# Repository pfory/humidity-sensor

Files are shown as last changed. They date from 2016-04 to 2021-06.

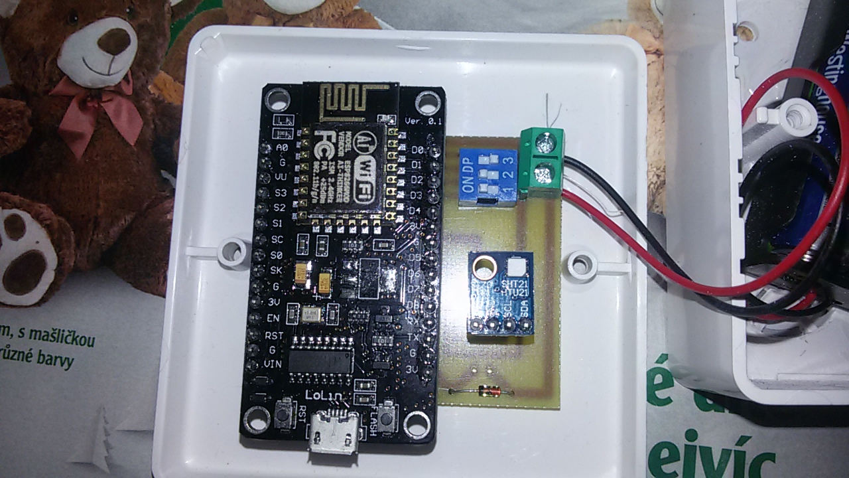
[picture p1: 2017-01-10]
pict/zařízení.jpg

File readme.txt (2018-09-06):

Vlhkomìr
--------
Zaøízení slouží k mìøení vlhkosti a teploty a odesílání hodnot na server xively.com. K pøenosu využívá bezdrátové pøipojení napø. k domácí síti. 
Konfigurace sí�ových adres, xively klíèù a intervalu mìøení je uživatelsky nastavitelná.

Pøepínaèe
Pohled ze strany souèástek 
---------
| O     |   Pøepínaè 3
| O     |   Pøepínaè 2
| O     |   Pøepínaè 1
---------
 ON  OFF
 x - libovolná poloha pøepínaèe

Zaøízení se mùže nacházet ve ètyøech režimech podle nastavení pøepínaèù 1,2 a 3.
            | 2         1           3
------------|------------------------------            
flash       | x         x           OFF
nastavení   | ON        ON          x
test mìøení | OFF       ON          x
mìøení      | OFF       OFF         ON

1. Flash FW
-----------
Pøepínaè 1 je v libovolné poloze, Pøepínaè 2 je v libovolné poloze, Pøepínaè 3 je v poloze OFF.

---------
|     O |   Pøepínaè 3
| x   x |   Pøepínaè 2
| x   x |   Pøepínaè 1
---------
 ON  OFF

Zaøízení musí být pøipojené k napájení, napájení z USB je kvùli spotøebì v režimu spánku vyøazené natrvalo z èinnosti.

2.Nastavení
-----------
Pøepínaè 1 je v poloze ON, Pøepínaè 2 je v poloze ON, Pøepínaè 3 je v libovolné poloze.

---------
| x   x |   Pøepínaè 3
| O     |   Pøepínaè 2
| O     |   Pøepínaè 1
---------
 ON  OFF

Zaøízení se pøepne do režimu AP (pøístupový bod). V seznamu Wifi sítí na PC se zobrazí nový pøístupový bod s názvem ESPHum, heslo pro pøipojení je "humidity007" bez uvozovek. 
Po zadaní adresy 192.168.4.1 v prohlížeèi se zobrazí formuláø pro nastavení sítì:
AP SSID - identifikaèní znak sítì ke které se bude zaøízení pøipojovat. Fusal2
AP PASSWORD - heslo k síti 1860918609
IP - adresa zaøízení napø. 192.168.1.200. Adresa musí být v rozsahu sítì, ke které se pøipojujeme. 192.168.0.93
Maska - sí�ová maska napø. 255.255.255.0
Gateway - brána napø. 192.168.1.1, pøístupový bod do internetu. 192.168.0.1
Prodleva mezi mìøeními - prodleva v sekundách mezi jednotlivými mìøeními. Doporuèuji nastavit více než 300s kvùli výdrži baterií.

Pøed uložením pøepnout Pøepínaè 2 (režim) do polohy ON (mìøení).
Nastavení se uloží a zaøízení se restartuje. Zaøízení je dále v režimu STA (stanice). 

3.Test Mìøení
-------------
Pøepínaè 1 je v poloze ON, Pøepínaè 2 je v poloze OFF, Pøepínaè 3 je v libovolné poloze.
---------
| x   x |   Pøepínaè 3
|     O |   Pøepínaè 2
| O     |   Pøepínaè 1
---------
 ON  OFF

Po zadání adresy IP zaøízení (nastavené v bodì 1.Nastavení) do prohlížeèe se zobrazí formuláø ve kterám se zobrazují namìøené údaje. 
Perioda mìøení je v tomto pøípadì 10s.

Namìøené údaje:
Teplota °C
Vlhkost %Rh
Napìtí baterie V

4.Mìøení
--------
Pøepínaè 1 je v poloze OFF, Pøepínaè 2 v poloze OFF, Pøepínaè 3 je v poloze ON.
---------
| O     |   Pøepínaè 3
|     O |   Pøepínaè 2
|     O |   Pøepínaè 1
---------
 ON  OFF

Zaøízení provede mìøení, výsledky odešle na Xively a upadne do režimu spánku s minimální spotøebou kolem 0,1mA. Po uplynutí nastavené prodlevy se celý cyklus opakuje.
V tomto pøípadì není možné zobrazit webový formuláø v prohlížeèi.

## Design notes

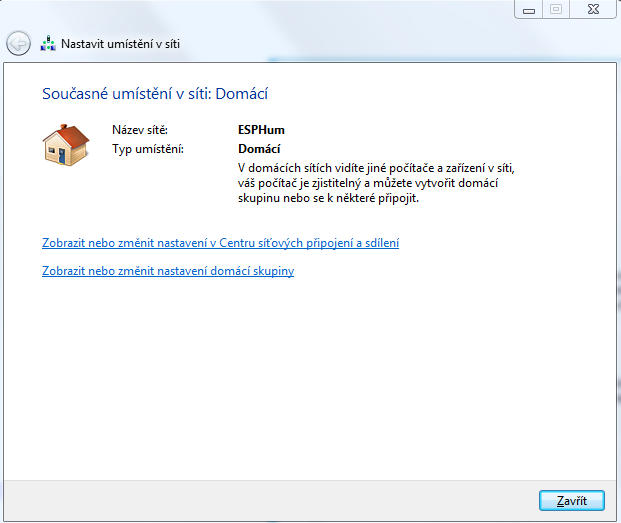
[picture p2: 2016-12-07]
pict/net02.PNG

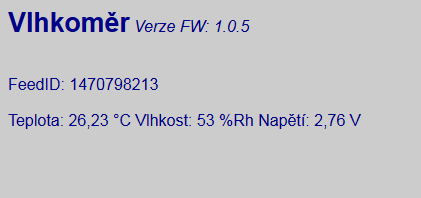
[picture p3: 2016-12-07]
pict/mode3web.PNG

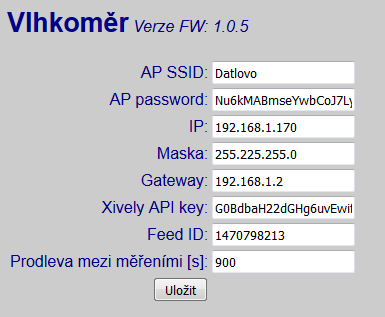
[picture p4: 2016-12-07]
pict/mode2web.PNG

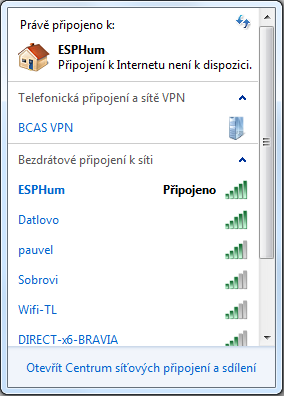
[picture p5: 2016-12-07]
pict/net04.PNG

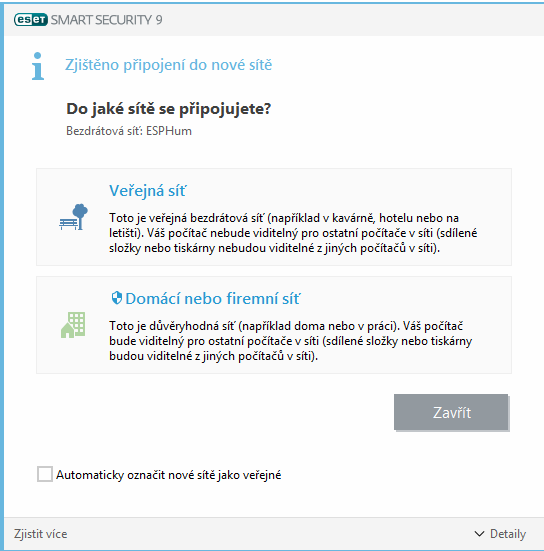
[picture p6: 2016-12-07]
pict/net03.PNG

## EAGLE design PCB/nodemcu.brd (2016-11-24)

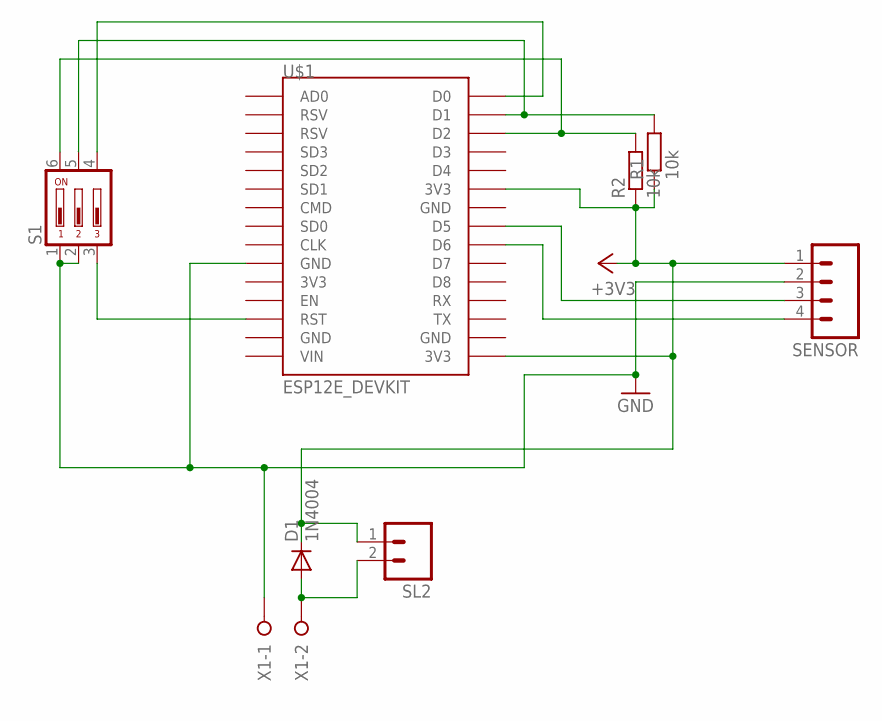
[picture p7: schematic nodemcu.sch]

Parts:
D1: 1N4004; DO41-10
R1, R2: 10k; 0207/10
S1: DIP03YL
SENSOR: M04; 04P
SL2: M02; 02P
U$1: ESP12E_DEVKIT
X1: W237-02P; W237-132

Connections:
+3V3: D1.C, R1.1, R2.1, SENSOR.1, SL2.1, U$1.3V3@1 (3V3), U$1.3V3@2 (3V3)
GND: S1.1, S1.2, SENSOR.2, U$1.GND@0 (GND), X1.1
unnamed: S1.4, U$1.D0
unnamed: SENSOR.4, U$1.D6
unnamed: SENSOR.3, U$1.D5
unnamed: S1.3, U$1.RST
unnamed: D1.A, SL2.2, X1.2
unnamed: R1.2, S1.5, U$1.D1
unnamed: R2.2, S1.6, U$1.D2

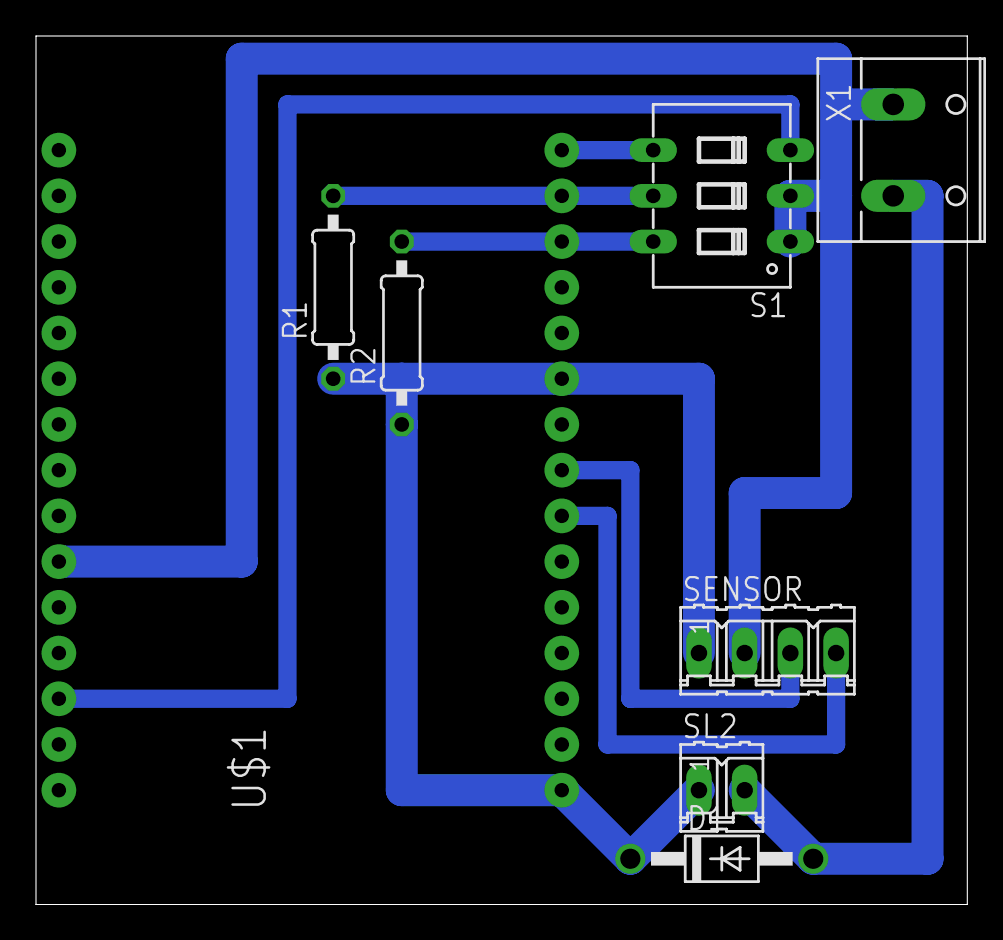
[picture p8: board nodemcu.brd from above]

Board: 2 copper layers, 51.7 x 48.2 mm, 8 parts (0 on the bottom side), 9 nets.

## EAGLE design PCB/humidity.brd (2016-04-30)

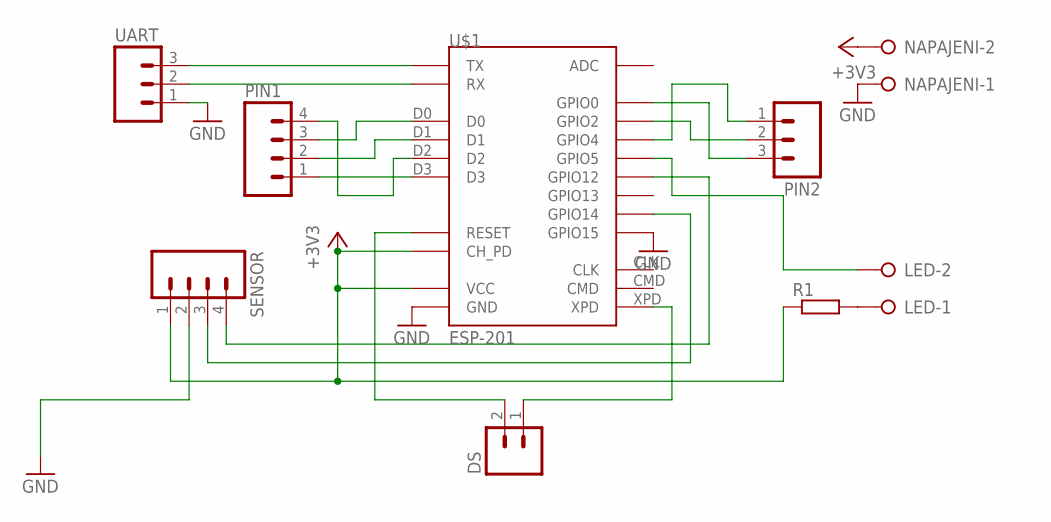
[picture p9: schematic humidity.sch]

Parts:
DS: M02; 02P
LED: W237-02P; W237-132
NAPAJENI: W237-02P; W237-132
PIN1: M04; 04P
PIN2: M03; 03P
R1: R-EU_0207/7; 0207/7
SENSOR: M04; 04P
U$1: ESP-201
UART: M03; 03P

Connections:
+3V3: NAPAJENI.2, R1.1, SENSOR.1, U$1.3V3 (VCC), U$1.3V3_2 (VCC), U$1.3V3_3 (VCC), U$1.CH_PD
GND: NAPAJENI.1, SENSOR.2, U$1.GND, U$1.GND_2 (GND), U$1.GND_3 (GND), U$1.GPIO15, UART.1
unnamed: PIN1.1, U$1.D3
unnamed: DS.2, U$1.RST (RESET)
unnamed: SENSOR.3, U$1.GPIO14
unnamed: SENSOR.4, U$1.GPIO12
unnamed: DS.1, U$1.XPD
unnamed: U$1.TX, UART.3
unnamed: U$1.RX, UART.2
unnamed: PIN1.2, U$1.D1
unnamed: PIN1.3, U$1.D0
unnamed: PIN1.4, U$1.D2
unnamed: PIN2.3, U$1.GPIO0
unnamed: PIN2.2, U$1.GPIO2
unnamed: LED.1, R1.2
unnamed: PIN2.1, U$1.GPIO4
unnamed: LED.2, U$1.GPIO5

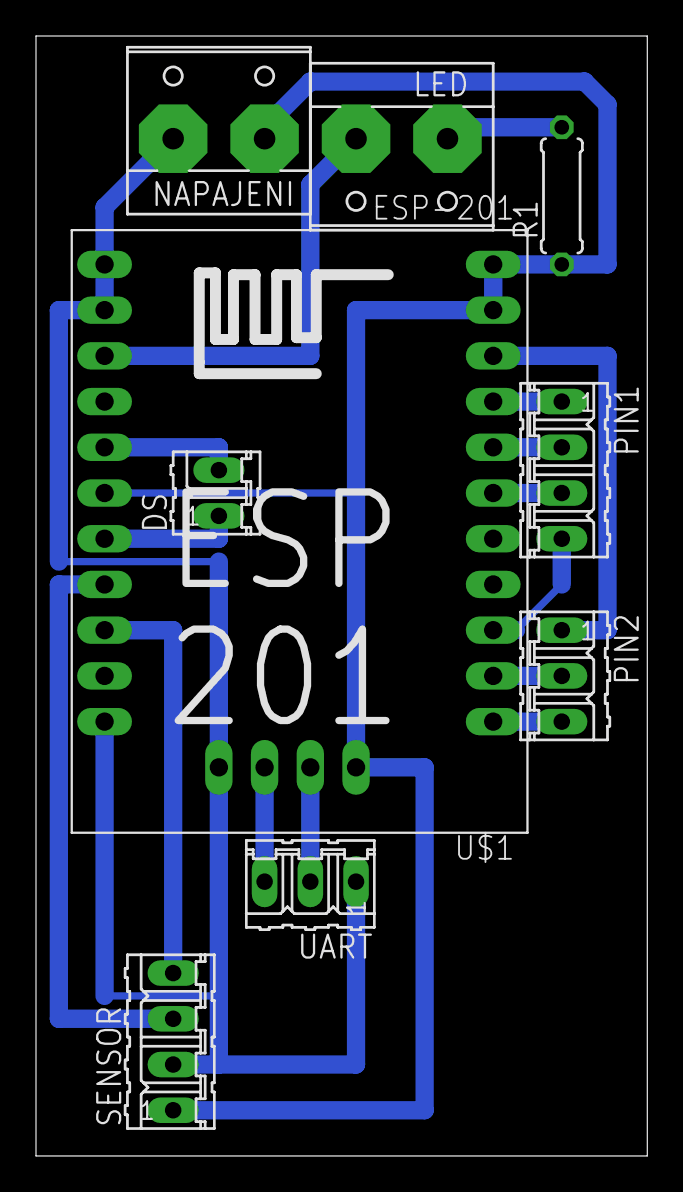
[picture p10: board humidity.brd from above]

Board: 2 copper layers, 34.0 x 62.2 mm, 9 parts (0 on the bottom side), 17 nets.

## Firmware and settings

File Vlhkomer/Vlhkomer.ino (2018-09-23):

unsigned long start=millis();

#include <ESP8266WiFi.h>
#include <SI7021.h>
#include <WiFiClient.h> 
#include <FS.h>
#include "Adafruit_MQTT.h"
#include "Adafruit_MQTT_Client.h"

#define verbose
#ifdef verbose
 #define DEBUG_PRINT(x)         Serial.print (x)
 #define DEBUG_PRINTDEC(x)      Serial.print (x, DEC)
 #define DEBUG_PRINTLN(x)       Serial.println (x)
 #define DEBUG_PRINTF(x, y)     Serial.printf (x, y)
 #define PORTSPEED 115200
#else
 #define DEBUG_PRINT(x)
 #define DEBUG_PRINTDEC(x)
 #define DEBUG_PRINTLN(x)
 #define DEBUG_PRINTF(x, y)
#endif 

ADC_MODE(ADC_VCC);

SI7021 sensor;

#define TEMPERATURE_DIVIDOR 100
#define MILIVOLT_TO_VOLT 1000.0
#define ONECYCLE_IN_MS 1000 
#define TIMEOUTFORWIFI_IN_MS 10000 
#define MICROSECOND 1000000
#define PORTSPEED 115200
#define MILLIS_TO_SEC 1000.0

#define SDA 12 // D6 - GPI12 on ESP-201 module
#define SCL 14 // D5 - GPI14 on ESP-201 module

#include <ESP8266WebServer.h>
ESP8266WebServer serverA(80);

unsigned long const sendDelay = 60000;
unsigned long lastSend = sendDelay;
unsigned long const dispDelay = 5000;
unsigned long lastDisp = dispDelay;
String sleepDelayInSeconds = "60"; 
String ssid;
String passw;
String ip;
String mask;
String gate;

//#define AIO_SERVER      "192.168.1.56"
#define AIO_SERVER      "178.77.238.20"
#define AIO_SERVERPORT  1883
#define AIO_USERNAME    "datel"
#define AIO_KEY         "hanka12"

String brokerIP;
String brokerPort;
String brokerUser;
String brokerPassword;

WiFiClient client;

#define MQTTBASE "/holcik/Vlhkomer3/"

Adafruit_MQTT_Client mqtt(&client, AIO_SERVER, AIO_SERVERPORT, AIO_USERNAME, AIO_KEY);
Adafruit_MQTT_Publish _temperature             = Adafruit_MQTT_Publish(&mqtt, MQTTBASE "Temperature");
Adafruit_MQTT_Publish _humidity                = Adafruit_MQTT_Publish(&mqtt, MQTTBASE "Humidity");
Adafruit_MQTT_Publish _bootTime                = Adafruit_MQTT_Publish(&mqtt, MQTTBASE "bootTime");
Adafruit_MQTT_Publish _voltage                 = Adafruit_MQTT_Publish(&mqtt, MQTTBASE "Voltage");
Adafruit_MQTT_Publish _versionSW               = Adafruit_MQTT_Publish(&mqtt, MQTTBASE "VersionSW");

#define MaxHeaderLength 1600
byte mode=1;
//D1 - prepinac 1 na GPIO5
//D2 - prepinac 2 na GPIO4
//byte mode=1;  //flash
//byte mode=2;  //setup   D1=0 D2=0
//byte mode=3;  //test    D1=1 D2=0
//byte mode=4;  //mereni  D1=1 D2=1

#include "FS.h"


String HttpHeader = String(MaxHeaderLength);
String HttpHeaderBak = String(MaxHeaderLength);

volatile float temperature;
volatile float humidity;
float voltage;

WiFiServer server(80);

float versionSW=1.1;
char versionSWString[] = "Vlhkoměr v"; //SW name & version

void handleRoot() {
	char temp[600];

	snprintf ( temp, 600,
      "<html>\
        <head>\
          <meta http-equiv='refresh' content='5'/>\
          <meta charset='UTF-8'>\
          <title>Vlhkomer</title>\
          <style>\
            body { background-color: #cccccc; font-family: Arial, Helvetica, Sans-Serif; Color: #000088; }\
          </style>\
        </head>\
        <body>\
          <span style='font-weight:bold; font-size:20pt;'>Vlhkoměr</span><span style='font-style:italic;'> Verze FW:1.1 Topic base: %s</span><br/><br/>\
          <p>Teplota: %3d,%02d °C Vlhkost: %3d \%Rh Napětí: %2d,%02d V</p>\
        </body>\
      </html>",
     MQTTBASE,
		 (int)(temperature/TEMPERATURE_DIVIDOR), ((int)temperature)%TEMPERATURE_DIVIDOR, (int)humidity, (int)voltage, ((int)(voltage*100.0))%100
	);
	serverA.send ( 200, "text/html", temp );
}

int readConfig(void);
bool startsWith(const char *, const char *);
String getValue(String, char, int);



void setup() {
  Serial.begin(PORTSPEED);
  DEBUG_PRINT(versionSWString);
  DEBUG_PRINTLN(versionSW);
  //mode
  pinMode(5, INPUT_PULLUP);
  pinMode(4, INPUT_PULLUP);
  int d1 = digitalRead(5);
  int d2 = digitalRead(4);
  
  if (d1==0 && d2==0) {
    mode=2;
  } else if (d1==1 && d2==0) {
    mode = 3;
  } else if (d1==1 && d2==1) {
    mode = 4;
  }
  DEBUG_PRINT("Mode:");
  DEBUG_PRINTLN(mode);

  if (mode==2) { //setup
    delay(1000);
    /* Set these to your desired credentials. */
    const char *ssid;
    const char *password;

    ssid = "ESPHum";
    password = "humidity007";

    DEBUG_PRINTLN();
    DEBUG_PRINT("Configuring access point...");
    /* You can remove the password parameter if you want the AP to be open. */
    WiFi.softAP(ssid, password);

    IPAddress myIP = WiFi.softAPIP();
    DEBUG_PRINT("AP IP address: ");
    DEBUG_PRINTLN(myIP);
    DEBUG_PRINT("SSID: ");
    DEBUG_PRINTLN(ssid);
    DEBUG_PRINT("Password: ");
    DEBUG_PRINTLN(password);
    server.begin();
    DEBUG_PRINTLN("HTTP server started");
    HttpHeader = "";
    
    readConfig();
    
  } else if (mode==3 || mode==4) { //test a mereni
    if (readConfig()>0) {
      DEBUG_PRINTLN("!!!!!!!!!!!!!!!!!!!!!!!!!!!!!!!!!!!!!!!!!!!!!!!!");
      DEBUG_PRINTLN("!!!! Zařízení není nakonfigurované, končím !!!!!");
      DEBUG_PRINTLN("!!!!!!!!!!!!!!!!!!!!!!!!!!!!!!!!!!!!!!!!!!!!!!!!");
      return;
    }
  
    char *pch;
    byte s[HttpHeaderBak.length()];
    HttpHeaderBak.getBytes(s, HttpHeaderBak.length());
    DEBUG_PRINTLN(HttpHeaderBak);
    pch = strtok((char*)s,"?&=");
    while (pch != NULL) {
     DEBUG_PRINTLN(pch);
    if (startsWith("ssid",pch)) {
      ssid=strchr(pch,'=')+1;
    }
    if (startsWith("passw",pch)) {
      passw=strchr(pch,'=')+1;
    }
    if (startsWith("ip",pch)) {
      ip=strchr(pch,'=')+1;
    }
    if (startsWith("mask",pch)) {
      mask=strchr(pch,'=')+1;
    }
    if (startsWith("gateway",pch)) {
      gate=strchr(pch,'=')+1;
    }

    // if (startsWith("brokerIP",pch)) {
      // brokerIP=strchr(pch,'=')+1;
    // }
    // if (startsWith("brokerPort",pch)) {
      // brokerPort=strchr(pch,'=')+1;
    // }
    // if (startsWith("brokerUser",pch)) {
      // brokerUser=strchr(pch,'=')+1;
    // }
    // if (startsWith("brokerPassword",pch)) {
      // brokerPassword=strchr(pch,'=')+1;
    // }

    if (startsWith("delay",pch)) {
      sleepDelayInSeconds=strchr(pch,'=')+1;
    }
    pch = strtok (NULL, "&");
    }

    IPAddress _ip(getValue(ip, '.', 0).toInt(), getValue(ip, '.', 1).toInt(), getValue(ip, '.', 2).toInt(), getValue(ip, '.', 3).toInt());
    IPAddress _gateway(getValue(gate, '.', 0).toInt(), getValue(gate, '.', 1).toInt(), getValue(gate, '.', 2).toInt(), getValue(gate, '.', 3).toInt());
    IPAddress _mask(getValue(mask, '.', 0).toInt(), getValue(mask, '.', 1).toInt(), getValue(mask, '.', 2).toInt(), getValue(mask, '.', 3).toInt());

    // Adafruit_MQTT_Client mqtt(&client, brokerIP.c_str(), (uint16_t)brokerPort.toInt(), brokerUser.c_str(), brokerPassword.c_str());
    /****************************** Feeds ***************************************/
    // Adafruit_MQTT_Publish _temperature             = Adafruit_MQTT_Publish(&mqtt, "/holcik/Vlhkomer5/Temperature");
    // Adafruit_MQTT_Publish _humidity                = Adafruit_MQTT_Publish(&mqtt, "/holcik/Vlhkomer5/Humidity");
    // Adafruit_MQTT_Publish _versionSW               = Adafruit_MQTT_Publish(&mqtt, "/holcik/Vlhkomer5/VersionSW");
    
    WiFi.mode(WIFI_STA);
    WiFi.config(_ip, _gateway, _mask);
    
    char _ssid[ssid.length()+1];
    char _passw[passw.length()+1];
    ssid.toCharArray(_ssid, ssid.length()+1);
    passw.toCharArray(_passw, passw.length()+1); 
    
    DEBUG_PRINTLN(_ssid);
    DEBUG_PRINTLN(_passw);

    WiFi.begin(_ssid, _passw);

    byte cyklu=0;  
    while (WiFi.status() != WL_CONNECTED) {
      cyklu++;
      delay(ONECYCLE_IN_MS);
      DEBUG_PRINT(".");
      if (cyklu*ONECYCLE_IN_MS>TIMEOUTFORWIFI_IN_MS) {
        DEBUG_PRINTLN();
        if (mode==3) {
          DEBUG_PRINT("Wifi unavailable, restart.");
          ESP.restart();
        } else {
          DEBUG_PRINT("Wifi unavailable, go to deepsleep for 5 minutes");
          ESP.deepSleep(300 * MICROSECOND, WAKE_RF_DEFAULT);
        }
      }
    }
    
    if (mode==4) {
      while (WiFi.status() != WL_CONNECTED) {
        cyklu++;
        delay(ONECYCLE_IN_MS);
        DEBUG_PRINT(".");
        if (cyklu*ONECYCLE_IN_MS>TIMEOUTFORWIFI_IN_MS) {
          DEBUG_PRINTLN();
          DEBUG_PRINT("Wifi unavailable, go to deepsleep for 5 minutes");
          ESP.deepSleep(300 * MICROSECOND, WAKE_RF_DEFAULT);
        }
      }
    }

    DEBUG_PRINTLN("");
    DEBUG_PRINTLN("WiFi connected");  
    DEBUG_PRINT("IP address: ");
    DEBUG_PRINTLN(WiFi.localIP());
    DEBUG_PRINT("Gateway: ");
    DEBUG_PRINTLN(WiFi.gatewayIP());
    DEBUG_PRINT("Subnet: ");
    DEBUG_PRINTLN(WiFi.subnetMask());
    DEBUG_PRINT("MAC: ");
    DEBUG_PRINTLN(WiFi.macAddress());
    DEBUG_PRINT("Interval: ");
    DEBUG_PRINT(sleepDelayInSeconds);
    DEBUG_PRINTLN(" seconds");

    sensor.begin(SDA,SCL);
    serverA.on ( "/", handleRoot );
  	serverA.begin();
    DEBUG_PRINTLN ( "HTTP server started" );
  }
}

void loop() {
  if (mode==2) {
    WiFiClient client = server.available();
      
    if (client) {
      while (client.connected()) {
        if (client.available()) {
           char c = client.read();
           //read MaxHeaderLength number of characters in the HTTP header
           //discard the rest until \n
           if (HttpHeader.length() < MaxHeaderLength) {
             //store characters to string
             HttpHeader = HttpHeader + c;
           }
           //if HTTP request has ended
           if (c == '\n') {
             if (HttpHeaderBak.length()>0) {
               HttpHeader=HttpHeaderBak;
               HttpHeaderBak="";
             }
             
             String key;
             
             char *pch;
             byte s[HttpHeader.length()];
             HttpHeader.getBytes(s, HttpHeader.length());
             pch = strtok((char*)s,"?&=");
             while (pch != NULL) {
               DEBUG_PRINTLN(pch);
              if (startsWith("ssid",pch)) {
                ssid=strchr(pch,'=')+1;
              }
              if (startsWith("passw",pch)) {
                passw=strchr(pch,'=')+1;
              }
              if (startsWith("ip",pch)) {
                ip=strchr(pch,'=')+1;
              }
              if (startsWith("mask",pch)) {
                mask=strchr(pch,'=')+1;
              }
              if (startsWith("gateway",pch)) {
                gate=strchr(pch,'=')+1;
              }
              // if (startsWith("brokerIP",pch)) {
                // brokerIP=strchr(pch,'=')+1;
              // }
              // if (startsWith("brokerPort",pch)) {
                // brokerPort=strchr(pch,'=')+1;
              // }
              // if (startsWith("brokerUser",pch)) {
                // brokerUser=strchr(pch,'=')+1;
              // }
              // if (startsWith("brokerPassword",pch)) {
                // brokerPassword=strchr(pch,'=')+1;
              // }
              if (startsWith("delay",pch)) {
                sleepDelayInSeconds=strchr(pch,'=')+1;
              }
              pch = strtok (NULL, "&");
             }

             
             // client.println("HTTP/1.1 200 OK");
             // client.println("Content-Type: text/html");
             // client.println("<html><head><meta charset='UTF-8'></head><body>");
             // client.println();
             client.print("<html><head><meta charset='UTF-8'></head><style> body { background-color: #cccccc; font-family: Arial, Helvetica, Sans-Serif; Color: #000088; }</style>");
             client.print("<form>");
             client.print("<span style='font-weight:bold; font-size:20pt;'>Vlhkoměr</span><span style='font-style:italic;'>v");
             client.print(versionSW);
             client.print("Topic base: ");
             client.print(MQTTBASE);             
             client.print("</span><br/><br/>");
             client.print("<table><tr><td style='text-align:right;'>AP SSID:</td><td><input type='text' name=ssid value='");
             client.print(ssid);
             client.print("'/></td></tr>");
             client.print("<tr><td style='text-align:right;'>AP password:</td><td><input type='text' name=passw value='" + passw + "'/></td></tr>");
             client.print("<tr><td style='text-align:right;'>IP:</td><td><input type='text' name='ip' maxlength='15' value='" + ip + "'/></td></tr>");
             client.print("<tr><td style='text-align:right;'>Maska:</td><td><input type='text' name='mask' maxlength='15' value='" + mask + "'/></td></tr>");
             client.print("<tr><td style='text-align:right;'>Gateway:</td><td><input type='text' name='gateway' maxlength='15' value='" + gate + "'/></td></tr>");
             // client.print("<tr><td style='text-align:right;'>MQTT Broker IP:</td><td><input type='text' name='brokerIP' maxlength='15' value='" + brokerIP + "'/></td></tr>");
             // client.print("<tr><td style='text-align:right;'>MQTT Broker port:</td><td><input type='text' name='brokerPort' maxlength='5' value='" + brokerPort + "'/></td></tr>");
             // client.print("<tr><td style='text-align:right;'>MQTT Broker user:</td><td><input type='text' name='brokerUser' maxlength='15' value='" + brokerUser + "'/></td></tr>");
             // client.print("<tr><td style='text-align:right;'>MQTT Broker password:</td><td><input type='text' name='brokerPassword' maxlength='15' value='" + brokerPassword + "'/></td></tr>");
             client.print("<tr><td style='text-align:right;'>Prodleva mezi měřeními [s]:</td><td><input type='text' name='delay' maxlength='5' value='" + sleepDelayInSeconds + "'/></td></tr>");
             client.print("<tr><td style='text-align:right'><input type=submit name=ulozit value='Uložit'></td>");
             // client.print("<td style='text-align:right'><input type=submit name=reset value='Reset'></td></tr>");
             client.print("</table></form>");
             client.print("</body></html>");

             if (HttpHeader.indexOf('?') > 0) {
              // open file for writing
              File f = SPIFFS.open("/config.txt", "w");
              if (!f) {
                  DEBUG_PRINTLN("file open failed");
              }
              DEBUG_PRINTLN("====== Writing to SPIFFS file =========");
              DEBUG_PRINT("HttpHeader:");
              DEBUG_PRINTLN(HttpHeader);
              // write 10 strings to file
              f.println(HttpHeader);
              f.close();
             }
             //clearing string for next read
             HttpHeader="";
             //stopping client
             client.stop();
          }
        }
      }
    }
  } else if (mode==3 || mode==4) {
    temperature=sensor.getCelsiusHundredths();
    humidity=sensor.getHumidityPercent();
    if (millis() - lastDisp >= dispDelay) {
      lastDisp = millis();
      DEBUG_PRINT("Temperature:");
      DEBUG_PRINT(temperature/TEMPERATURE_DIVIDOR);
      DEBUG_PRINTLN("C");
      DEBUG_PRINT("Humidity:");
      DEBUG_PRINT(humidity);
      DEBUG_PRINTLN("%");
      voltage = (float)ESP.getVcc()/MILIVOLT_TO_VOLT;
      DEBUG_PRINT("Voltage:");
      DEBUG_PRINT(voltage);
      DEBUG_PRINTLN("V");
      DEBUG_PRINTLN();
    }
    if (mode==3) {
      serverA.handleClient();
    }
    if (millis() - lastSend >= sendDelay) {
      lastSend = millis();
      //send MQTT data
      sendDataHA();
    }
    if (mode==4) { //mererni
      DEBUG_PRINT("Start duration:");
      DEBUG_PRINT(millis()-start);
      DEBUG_PRINTLN(" ms.");
      DEBUG_PRINTLN("Entering deep sleep mode.");
      DEBUG_PRINT("Wake in ");
      DEBUG_PRINT(sleepDelayInSeconds);
      DEBUG_PRINTLN(" s.");
      delay(2000);
      ESP.deepSleep(sleepDelayInSeconds.toInt() * MICROSECOND, WAKE_RF_DEFAULT);
    }
  }
}

bool startsWith(const char *pre, const char *str) {
    size_t lenpre = strlen(pre),
           lenstr = strlen(str);
    return lenstr < lenpre ? false : strncmp(pre, str, lenpre) == 0;
}


int readConfig() {
  DEBUG_PRINTLN("Read config file.");
  SPIFFS.begin();
  // open file for reading
  File f = SPIFFS.open("/config.txt", "r");
  if (!f) {
    DEBUG_PRINTLN("file open failed");
    return 1;
  } else {
    DEBUG_PRINTLN("====== Reading from SPIFFS file =======");
    HttpHeaderBak=f.readStringUntil('\n');
    DEBUG_PRINTLN(HttpHeaderBak);
  }
  return 0;
}


String getValue(String data, char separator, int index) {
  int found = 0;
  int strIndex[] = {0, -1};
  int maxIndex = data.length()-1;

  for(int i=0; i<=maxIndex && found<=index; i++){
    if(data.charAt(i)==separator || i==maxIndex){
        found++;
        strIndex[0] = strIndex[1]+1;
        strIndex[1] = (i == maxIndex) ? i+1 : i;
    }
  }

  return found>index ? data.substring(strIndex[0], strIndex[1]) : "";
}

void sendDataHA() {
  DEBUG_PRINTLN(" I am sending data from humidity and temperature sensor to HomeAssistant");
  MQTT_connect();
  if (! _temperature.publish(temperature/TEMPERATURE_DIVIDOR)) {
    DEBUG_PRINTLN("Temperature failed");
  } else {
    DEBUG_PRINTLN("Temperature OK!");
  }  
  if (! _humidity.publish(humidity)) {
    DEBUG_PRINTLN("Humidity failed");
  } else {
    DEBUG_PRINTLN("Humidity OK!");
  }  
  if (! _voltage.publish(voltage)) {
    DEBUG_PRINTLN("Voltage failed");
  } else {
    DEBUG_PRINTLN("Voltage OK!");
  }  
  if (! _bootTime.publish((uint8_t)(millis()-start))) {
    DEBUG_PRINTLN("BootTime failed");
  } else {
    DEBUG_PRINTLN("BootTime OK!");
  }  
  if (! _versionSW.publish(versionSW)) {
    DEBUG_PRINTLN("Version SW failed");
  } else {
    DEBUG_PRINTLN("Version SW OK!");
  }  
}
 
void MQTT_connect() {
  int8_t ret;

  // Stop if already connected.
  if (mqtt.connected()) {
    return;
  }

  DEBUG_PRINT("Connecting to MQTT... ");

  uint8_t retries = 3;
  while ((ret = mqtt.connect()) != 0) { // connect will return 0 for connected
       DEBUG_PRINTLN(mqtt.connectErrorString(ret));
       DEBUG_PRINTLN("Retrying MQTT connection in 5 seconds...");
       mqtt.disconnect();
       delay(5000);  // wait 5 seconds
       retries--;
       if (retries == 0) {
         // basically die and wait for WDT to reset me
         while (1);
       }
  }
  DEBUG_PRINTLN("MQTT Connected!");
}

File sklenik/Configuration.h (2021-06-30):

#ifndef CONFIGURATION_H
#define CONFIGURATION_H

#include <ESP8266WiFi.h>              //https://github.com/esp8266/Arduino
#include <WiFiManager.h>              //https://github.com/tzapu/WiFiManager
#include "Sender.h"
#include <DoubleResetDetector.h>      //https://github.com/khoih-prog/ESP_DoubleResetDetector
#include <Ticker.h>
#include "SI7021.h"                   //https://github.com/LowPowerLab/SI7021.git


//SW name & version
#define     VERSION                      "0.20"
#define     SW_NAME                      "VlhkomerSklenik"

//#define timers
#define verbose
//#define time
#ifdef time
#include <TimeLib.h>
#include <Timezone.h>
#endif

#define AUTOCONNECTPWD    "password"

//#define ota
#ifdef ota
#include <ArduinoOTA.h>
#define HOSTNAMEOTA       SW_NAME VERSION
#define AUTOCONNECTNAME   HOSTNAMEOTA
#else
#define AUTOCONNECTNAME   SW_NAME VERSION
#endif

/*
--------------------------------------------------------------------------------------------------------------------------

Version history:

--------------------------------------------------------------------------------------------------------------------------
HW
ESP8266 Wemos D1
HC-SR04
*/


#define verbose
#ifdef verbose
  #define DEBUG_PRINT(x)         Serial.print (x)
  #define DEBUG_PRINTDEC(x)      Serial.print (x, DEC)
  #define DEBUG_PRINTLN(x)       Serial.println (x)
  #define DEBUG_PRINTF(x, y)     Serial.printf (x, y)
  #define DEBUG_PRINTHEX(x)      Serial.print (x, HEX)
  #define PORTSPEED 115200
  #define SERIAL_BEGIN           Serial.begin(PORTSPEED);
#else
  #define DEBUG_PRINT(x)
  #define DEBUG_PRINTDEC(x)
  #define DEBUG_PRINTLN(x)
  #define DEBUG_PRINTF(x, y)
#endif 


// Number of seconds after reset during which a
// subseqent reset will be considered a double reset.
#define DRD_TIMEOUT 2
// RTC Memory Address for the DoubleResetDetector to use
#define DRD_ADDRESS 0

#define CONFIG_PORTAL_TIMEOUT 60 //jak dlouho zustane v rezimu AP nez se cip resetuje
#define CONNECT_TIMEOUT 120 //jak dlouho se ceka na spojeni nez se aktivuje config portal

static const char* const      mqtt_server                    = "192.168.1.56";
static const uint16_t         mqtt_port                      = 1883;
static const char* const      mqtt_username                  = "datel";
static const char* const      mqtt_key                       = "hanka12";
static const char* const      mqtt_base                      = "/home/sklenik/esp10";


int                           voltage                        = 0; //voltage in mV
uint32_t                      lastRun                        = 0;
int                           temperature                    = 0;
uint8_t                       humidity                       = 0;
uint32_t                      deepSleepMicros                = 0;


#define TEMPERATURE_DIVIDOR                 100


#define SCL                                 14 //                       GPIO14
#define SDA                                 12 //                       GPIO12
//#define BUILTIN_LED                         1


#endif

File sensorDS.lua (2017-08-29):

--Init  
bootTime                   = tmr.now()
base                       = "/home/sklenik/esp10/"
deviceID                   = "ESP8266 Sklenik "..node.chipid()
maxStartTime               = 10000 --10sec
sleepDelayWhenNoConnection = 3600000000 --1 hour
microsToSec                = 1000000
tempAndHumidityKoef        = 100
mVoltsToVolts              = 1000

--- INTERVAL ---
-- In seconds. Remember that the sensor reading, 
-- reboot and wifi reconnect takes a few seconds
time_between_sensor_readings = 3600  --1 hour


tmr.alarm(1, maxStartTime, tmr.ALARM_SINGLE, function()
  print("No connection. Going to sleep for 600 sec.")
  node.dsleep(sleepDelayWhenNoConnection)
end)

if adc.force_init_mode(adc.INIT_VDD33)
then
  node.restart()
  return -- don't bother continuing, the restart is scheduled
end

napeti = adc.readvdd33()/mVoltsToVolts
print("Napeti baterie: "..napeti.." V")

Broker="192.168.1.56"  

versionSW         = 0.4
versionSWString   = "Sklenik v" 
print(versionSWString .. versionSW)

si7021 = require("si7021")
SDA_PIN = 6 -- sda pin, GPIO12
SCL_PIN = 5 -- scl pin, GPIO14
si7021.init(SDA_PIN, SCL_PIN)

function sendData()
  si7021.read(OSS)
  h = si7021.getHumidity()/tempAndHumidityKoef
  if (h>100) then h=100 end
  t = si7021.getTemperature()/tempAndHumidityKoef
  napeti = adc.readvdd33()/mVoltsToVolts
  if napeti==nil then napeti=0 end

  print("Humidity: "..h.." %")
  print("Temperature: "..t.." C")
  print("Voltage:"..napeti.." V")
  m:publish(base.."temperature",                    string.format("%.1f",t),0,0, function(conn)
    m:publish(base.."humidity",                     string.format("%.1f",h),0,0, function(conn)
      m:publish(base.."voltage",                    string.format("%.2f",napeti),0,0, function(conn)   
        m:publish(base.."bootTime",                 string.format("%.2f",(tmr.now()-bootTime)/microsToSec),0,0, function(conn)   
          m:publish(base.."VersionSW",              string.format("%.2f",versionSW),0,0, function(conn)   
            print("Boot time:"..((tmr.now()-bootTime)/microsToSec))
            time_between_sensor_readings = time_between_sensor_readings - ((tmr.now()-bootTime) / microsToSec)
            print("Going to sleep for "..time_between_sensor_readings.." sec.")
            node.dsleep(time_between_sensor_readings*microsToSec)
          end)
        end)
      end)
    end)
  end)
end

m = mqtt.Client(deviceID, 180, "datel", "hanka12")  

m:connect(Broker, 1883, 0, 1, function(conn) 
  --mqtt_sub() --run the subscription function 
  --print(wifi.sta.getip())
  print("Mqtt Connected to:" .. Broker.." - "..base) 
  sendData() 
end)

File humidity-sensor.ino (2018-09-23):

/*
Vlhomer ESP8266-201
*/

#include <SI7021.h>
#include <ESP8266WiFi.h>
#include <WiFiClient.h>
//#include <ESP8266WebServer.h>
#include "Adafruit_MQTT.h"
#include "Adafruit_MQTT_Client.h"
#include <WiFiManager.h> 

//for LED status
#include <Ticker.h>

unsigned long       start=0;
unsigned long       bootTime;

Ticker ticker;

void tick()
{
  //toggle state
  int state = digitalRead(BUILTIN_LED);  // get the current state of GPIO1 pin
  digitalWrite(BUILTIN_LED, !state);     // set pin to the opposite state
}
  
//#define PORADI1
#define PORADI2
  
#define verbose
#ifdef verbose
 #define DEBUG_PRINT(x)         Serial.print (x)
 #define DEBUG_PRINTDEC(x)      Serial.print (x, DEC)
 #define DEBUG_PRINTLN(x)       Serial.println (x)
 #define DEBUG_PRINTF(x, y)     Serial.printf (x, y)
 #define PORTSPEED 115200
#else
 #define DEBUG_PRINT(x)
 #define DEBUG_PRINTDEC(x)
 #define DEBUG_PRINTLN(x)
 #define DEBUG_PRINTF(x, y)
#endif 
  

#define AIO_SERVER      "192.168.1.56"
//#define AIO_SERVER      "178.77.238.20"
#define AIO_SERVERPORT  1883
#define AIO_USERNAME    "datel"
#define AIO_KEY         "hanka12"

WiFiClient client;

Adafruit_MQTT_Client mqtt(&client, AIO_SERVER, AIO_SERVERPORT, AIO_USERNAME, AIO_KEY);

/****************************** Feeds ***************************************/
#ifdef PORADI1
#define MQTTBASE "/home/Vlhkomer/1/"
#endif
#ifdef PORADI2
#define MQTTBASE "/home/Vlhkomer/2/"
#endif
Adafruit_MQTT_Publish _temperature             = Adafruit_MQTT_Publish(&mqtt, MQTTBASE "Temperature");
Adafruit_MQTT_Publish _humidity                = Adafruit_MQTT_Publish(&mqtt, MQTTBASE "Humidity");
Adafruit_MQTT_Publish _bootTime                = Adafruit_MQTT_Publish(&mqtt, MQTTBASE "bootTime");
Adafruit_MQTT_Publish _voltage                 = Adafruit_MQTT_Publish(&mqtt, MQTTBASE "Voltage");
Adafruit_MQTT_Publish _versionSW               = Adafruit_MQTT_Publish(&mqtt, MQTTBASE "VersionSW");

#ifdef PORADI1
IPAddress _ip           = IPAddress(192, 168, 1, 111);
#endif
#ifdef PORADI2
IPAddress _ip           = IPAddress(192, 168, 1, 112);
#endif
IPAddress _gw           = IPAddress(192, 168, 1, 1);
IPAddress _sn           = IPAddress(255, 255, 255, 0);


void MQTT_connect(void);

extern "C" {
  #include "user_interface.h"
}

volatile float temperature;
volatile float humidity;
float voltage;

SI7021 sensor;

unsigned int sleepDelayInSeconds = 600; //10 min

#define TEMPERATURE_DIVIDOR 100
#define MILIVOLT_TO_VOLT 1000.0
#define MILISECOND_TO_SECOND 1000.0
#define MICROSECOND 1000000


#define SDA 12 // D6 - GPI12 on ESP-201 module
#define SCL 14 // D5 - GPI14 on ESP-201 module

//gets called when WiFiManager enters configuration mode
void configModeCallback (WiFiManager *myWiFiManager) {
  Serial.println("Entered config mode");
  Serial.println(WiFi.softAPIP());
  //if you used auto generated SSID, print it
  Serial.println(myWiFiManager->getConfigPortalSSID());
  //entered config mode, make led toggle faster
  ticker.attach(0.2, tick);
}

ADC_MODE(ADC_VCC);

float versionSW                   = 0.2;
#ifdef PORADI1
String versionSWString            = "Vlhomer#1 v";
#endif
#ifdef PORADI2
String versionSWString            = "Vlhomer#2 v";
#endif
uint32_t heartBeat                = 0;

void setup() {
  start = millis();
#ifdef verbose
  Serial.begin(PORTSPEED);
#endif
  DEBUG_PRINTLN();
  DEBUG_PRINT(versionSWString);
  DEBUG_PRINTLN(versionSW);
  DEBUG_PRINT("START:");
  DEBUG_PRINTLN(start);
  //set led pin as output
  pinMode(BUILTIN_LED, OUTPUT);
  // start ticker with 0.5 because we start in AP mode and try to connect
  ticker.attach(0.6, tick);
  
  DEBUG_PRINTLN(ESP.getResetReason());
  if (ESP.getResetReason()=="Software/System restart") {
    heartBeat=1;
  } else if (ESP.getResetReason()=="Power on") {
    heartBeat=2;
  } else if (ESP.getResetReason()=="External System") {
    heartBeat=3;
  } else if (ESP.getResetReason()=="Hardware Watchdog") {
    heartBeat=4;
  } else if (ESP.getResetReason()=="Exception") {
    heartBeat=5;
  } else if (ESP.getResetReason()=="Software Watchdog") {
    heartBeat=6;
  } else if (ESP.getResetReason()=="Deep-Sleep Wake") {
    heartBeat=7;
  }

  //WiFiManager
  WiFiManager wifiManager;
  //set callback that gets called when connecting to previous WiFi fails, and enters Access Point mode
  wifiManager.setSTAStaticIPConfig(_ip, _gw, _sn);
  wifiManager.setAPCallback(configModeCallback);
  
  #ifdef PORADI1
  if (!wifiManager.autoConnect("Vlhkomer1", "password")) {
  #endif
  #ifdef PORADI2
  if (!wifiManager.autoConnect("Vlhkomer2", "password")) {
  #endif
    DEBUG_PRINTLN("failed to connect, we should reset as see if it connects");
    delay(3000);
    ESP.reset();
    delay(5000);
  }

	DEBUG_PRINTLN("");
	DEBUG_PRINT("Connected to ");
	DEBUG_PRINT("IP address: ");
	DEBUG_PRINTLN(WiFi.localIP());
  
  sensor.begin(SDA,SCL);
  
  ticker.detach();
  //keep LED on
  digitalWrite(BUILTIN_LED, HIGH);
}

void loop() {
  MQTT_connect();

  DEBUG_PRINT("Meassurement....");
  temperature=sensor.getCelsiusHundredths();
  humidity=sensor.getHumidityPercent();
  DEBUG_PRINTLN("DONE");
  DEBUG_PRINT("Temperature:");
  DEBUG_PRINT(temperature/TEMPERATURE_DIVIDOR);
  DEBUG_PRINTLN("C");
  DEBUG_PRINT("Humidity:");
  DEBUG_PRINT(humidity);
  DEBUG_PRINTLN("%");
  voltage = (float)ESP.getVcc()/MILIVOLT_TO_VOLT;
  DEBUG_PRINT("Voltage:");
  DEBUG_PRINT(voltage);
  DEBUG_PRINTLN("V");
  DEBUG_PRINTLN();

  if (! _temperature.publish(temperature/TEMPERATURE_DIVIDOR)) {
    DEBUG_PRINTLN("Temperature failed");
  } else {
    DEBUG_PRINTLN("Temperature OK!");
  }  
  if (! _humidity.publish(humidity)) {
    DEBUG_PRINTLN("Humidity failed");
  } else {
    DEBUG_PRINTLN("Humidity OK!");
  }  
  if (! _voltage.publish(voltage)) {
    DEBUG_PRINTLN("Voltage failed");
  } else {
    DEBUG_PRINTLN("Voltage OK!");
  }  
  if (! _versionSW.publish(versionSW)) {
    DEBUG_PRINTLN("Version SW failed");
  } else {
    DEBUG_PRINTLN("Version SW OK!");
  }  
  
  //boot time
  bootTime = millis()-start;
  DEBUG_PRINT("END:");
  DEBUG_PRINTLN(millis());
  if (! _bootTime.publish((float)(bootTime/MILISECOND_TO_SECOND))) {
    DEBUG_PRINTLN("BootTime failed");
  } else {
    DEBUG_PRINTLN("BootTime OK!");
  }  
    
  DEBUG_PRINT("Start duration:");
  DEBUG_PRINT(bootTime);
  DEBUG_PRINTLN(" ms.");
  DEBUG_PRINTLN("Entering deep sleep mode.");
  DEBUG_PRINT("Wake in ");
  DEBUG_PRINT(sleepDelayInSeconds);
  DEBUG_PRINTLN(" s.");
  delay(1000);
  ESP.deepSleep(sleepDelayInSeconds * MICROSECOND, WAKE_RF_DEFAULT);
}
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

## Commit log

2016-04-25 upravena DPS
    [humidity.brd]
2016-05-11 +code for arduino ide
2016-06-28 verze pro Holcika
    [fyzika_konstanty.xlsm]
2016-11-07 +schema a spoj
    [nodemcu.brd, nodemcu.sch]
2016-11-09 uprava desky
    [nodemcu.brd, nodemcu.sch]
2016-11-15 upraveno schema pro dip switch
    [nodemcu.brd, nodemcu.sch]
2016-11-16 upravy spoje
    [nodemcu.brd, nodemcu.sch]
2016-11-22 změna tlouštky spojů
    [nodemcu.brd]
2016-12-01 zmena adc mode
2016-12-08 přeskupeno
    [humidity.brd, humidity.sch, nodemcu.brd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]
2018-09-06 pridan arduino projekt pro esp8266-201
2020-07-23 + sensor s deep sleep pro sklenik
    [configuration.h]
2021-01-07 verze pro Arduino IDE a ESP201
    [Configuration.h]
2021-06-30 opravena chyba s delkou bootu
    [Configuration.h]
